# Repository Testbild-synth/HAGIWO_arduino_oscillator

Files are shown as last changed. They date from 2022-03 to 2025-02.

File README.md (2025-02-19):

# HAGIWO 019/022/023 Triple Oscillator (FM/CHORD/ADDITIVE)
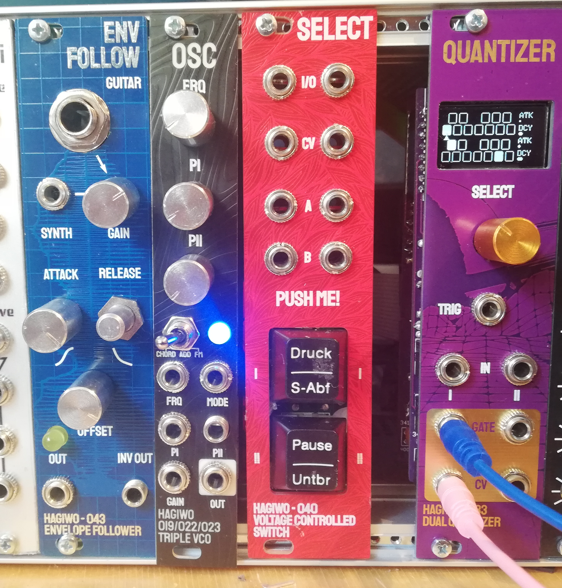
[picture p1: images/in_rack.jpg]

4HP through hole version of the HAGIWO FM/additive/chord oscillator with mode switch and gain input.

This module is basically my PCB version of the HAGIWO osc, heavily inspired by [luis lutz version](https://github.com/luislutz/Arduino-VDCO).
The main difference is since I could not get his code to work without major audio problems, I rewrote the entire thing myself.

The module combines three different oscillators from HAGIWO,  with a mode switch (and mode cv input) to switch between them.
Additionally, it has a gain input that normals so that it is only used when you plug in a jack.

### STATUS: Revision 1.1 PCB with slight modifications to make the build easier.

## Hardware and PCB
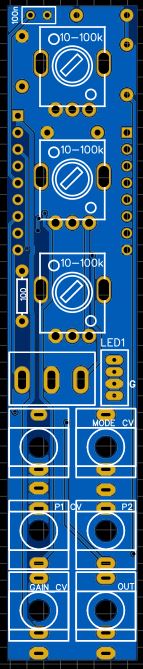
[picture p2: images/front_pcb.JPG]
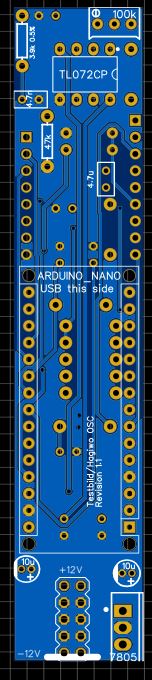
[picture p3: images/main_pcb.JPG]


You can find the schematic and BOM in the root folder.
For the potentiometers, any value between 10k and 100k should be fine.

The module has three PCBs: a panel PCB, a main PCB and a controls pcb.
You can order them on any common PCB manufacturing service, I used JLCPCB. For the circuit PCBs, standard settings should be fine.
For the panel, since it has copper exposed, make sure to choose a lead free surface finish (LeadFree HASL, ENIG) and/or spraypaint your panels so that you don't get lead on your hands.

Assembly is pretty straight forward. Since it is so crowded, make sure to do the resistors first before the headers so you have more space to work.

Also make sure to put the headers connecting both PCBs in the correct direction so that the arduino faces to the back.

The only thing there is to tune is a trimpot that sets output gain (as arduino is 0-5V output and I wanted to be able to make mine louder). Tune it to your liking.

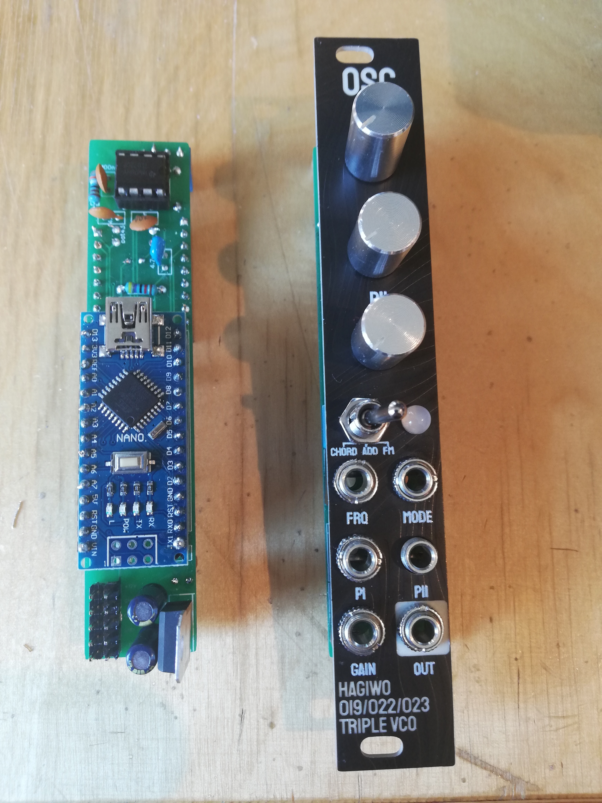
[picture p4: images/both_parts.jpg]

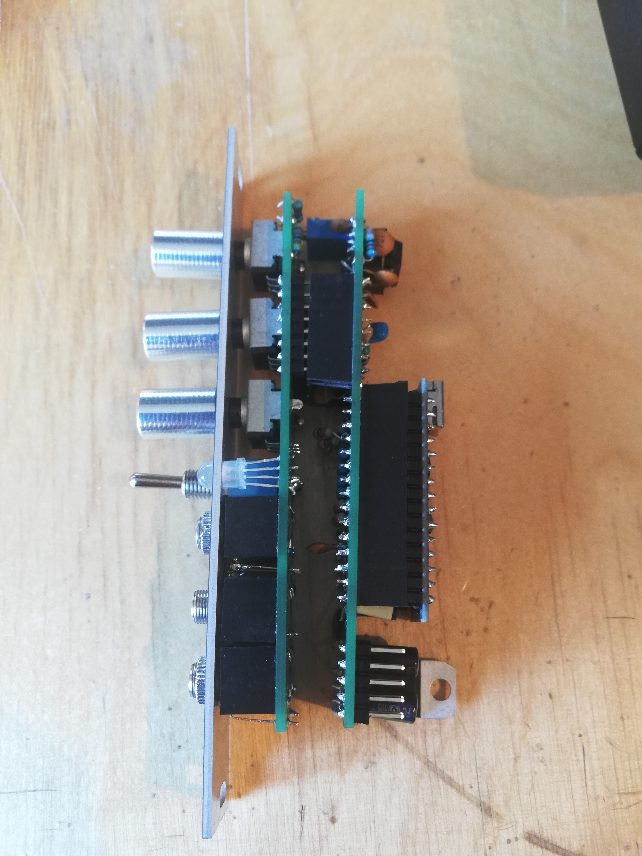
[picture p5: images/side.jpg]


## Build

Most of the build is relatively straight forward. be sure to actually have fitting values for the resistors that need to be precise. These are indicated with % on the board and in the bom.      
One thing to watch out for is that due to size constraints I oriented one row of thonkiconn jacks to face another one and have the grounds go into the same hole.
So top two rows face each other, ground legs go into the same hole.

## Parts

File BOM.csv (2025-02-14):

Name | Designator | Footprint | Quantity | Part/Comment | Link
4.7n | C1,C2,C3,C4 | RAD-0.1 | 4 | through hole ceramic capacitor
10n | C5 | RAD-0.1 | 1 | through hole ceramic capacitor
4.7u | C6 | RAD-0.1 | 1 | through hole ceramic capacitor
10u | C7,C8 | CAP-D4.0×F1.5 | 2 | through hole electrolytic capacitor, 25v
100n | C9,C10,C11,C12 | RAD-0.1 | 4 | through hole ceramic capacitor
BAT43 | D1,D2 | DO-34_BD1.6-L3.0-P7.00-D0.6-RD | 2 | through hole schottky diode
EURORACK_POWERHEADER | EP1 | EURORACK_POWER | 1 | Power header
10-100k | FRQ,P1_POT,P2_POT | R09-5KΩ | 3 | Rv09 Style Potentiometer. | https://de.aliexpress.com/item/1005002222402620.html
100k | GAIN | TRIMPOT | 1 | through hole trimpot | https://de.aliexpress.com/item/1005006157105408.html
Header-Male-2.54_1x8 | H1,H2 | HDR-TH_8P-P2.54-V-M | 2 | Male and female 2.54mm header 1x8
HDR-M-2.54_1x9 | J1,J6 | HDR-M-2.54_1X9 | 2 | Male and female 2.54mm header 1x9
P1_CV, MODE_CV, P2CV,GAIN_CV,V_OCT,OUT | J2, J3, J4, J5, J7, J8 | THONKICONN_1 | 6 | Thonkiconn mono 3.5mm jack | https://de.aliexpress.com/item/4000105739424.html cheapest I could get
LED RGB | LED1 | GEK_RGB_LED | 1 | 4 pin RGB led, like this: | https://www.reichelt.de/de/de/shop/produkt/led_5_mm_bedrahtet_4-pin_rot_gruen_blau_700_1300_300_mcd_60-231040
22k | R1,R2,R7 | R_AXIAL-0.3 | 3 | through hole resistor
499k 0.5% | R3 | R_AXIAL-0.3 | 1 | through hole resistor (accuracy important)
3.9k 0.5% | R4,R9 | R_AXIAL-0.3 | 2 | through hole resistor (accuracy important)
4k7 | R5,R6,R8 | R_AXIAL-0.3 | 3 | through hole resistor
220 | R10 | R_AXIAL-0.3 | 1 | through hole resistor
47k | R11,R14 | R_AXIAL-0.3 | 2 | through hole resistor
100 | R12 | R_AXIAL-0.3 | 1 | through hole resistor
330k | R13 | R_AXIAL-0.3 | 1 | through hole resistor
1k | R15 | R_AXIAL-0.3 | 1 | through hole resistor
68k | R16 | R_AXIAL-0.3 | 1 | through hole resistor
ARDUINO_NANO | U1 | ARDUINO_NANO_WITHMOUNTINGHOLES | 1 | It’s an arduino
7805 | U3 | TO-220-3_L10.0-W4.5-P2.54-L | 1 | L7805CV-DG Voltage regulator
TOGGLE SWITCH SPDT | U4 | MINI TOGGLE SWITCH SPDT ON-ON | 1 | Mini Toggle Switch SPDT On-OFF-ON MST 103 style | https://de.aliexpress.com/item/4000638047913.html
TL072CP | U2 | DIP-8_L9.4-W6.4-P2.54-LS9.1-BL | 1 | TL072CP DIP8 opamp

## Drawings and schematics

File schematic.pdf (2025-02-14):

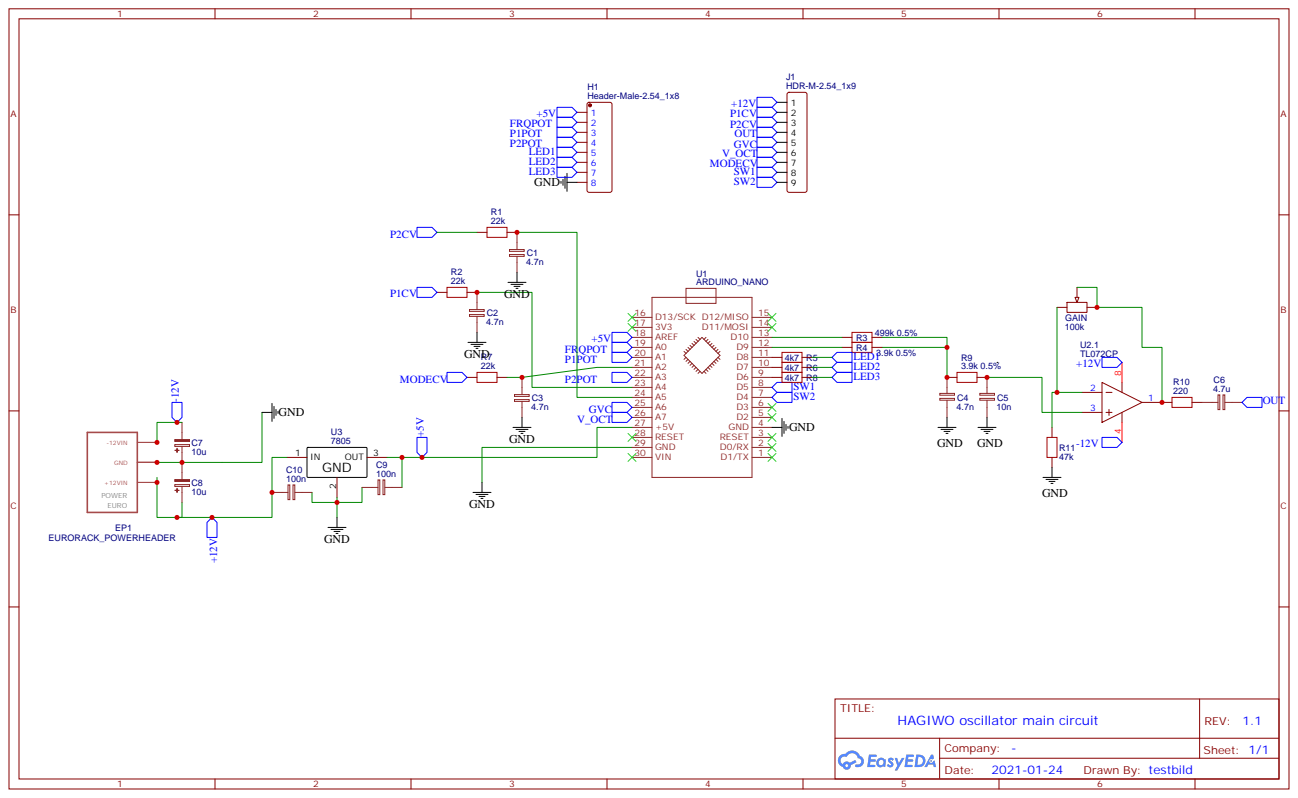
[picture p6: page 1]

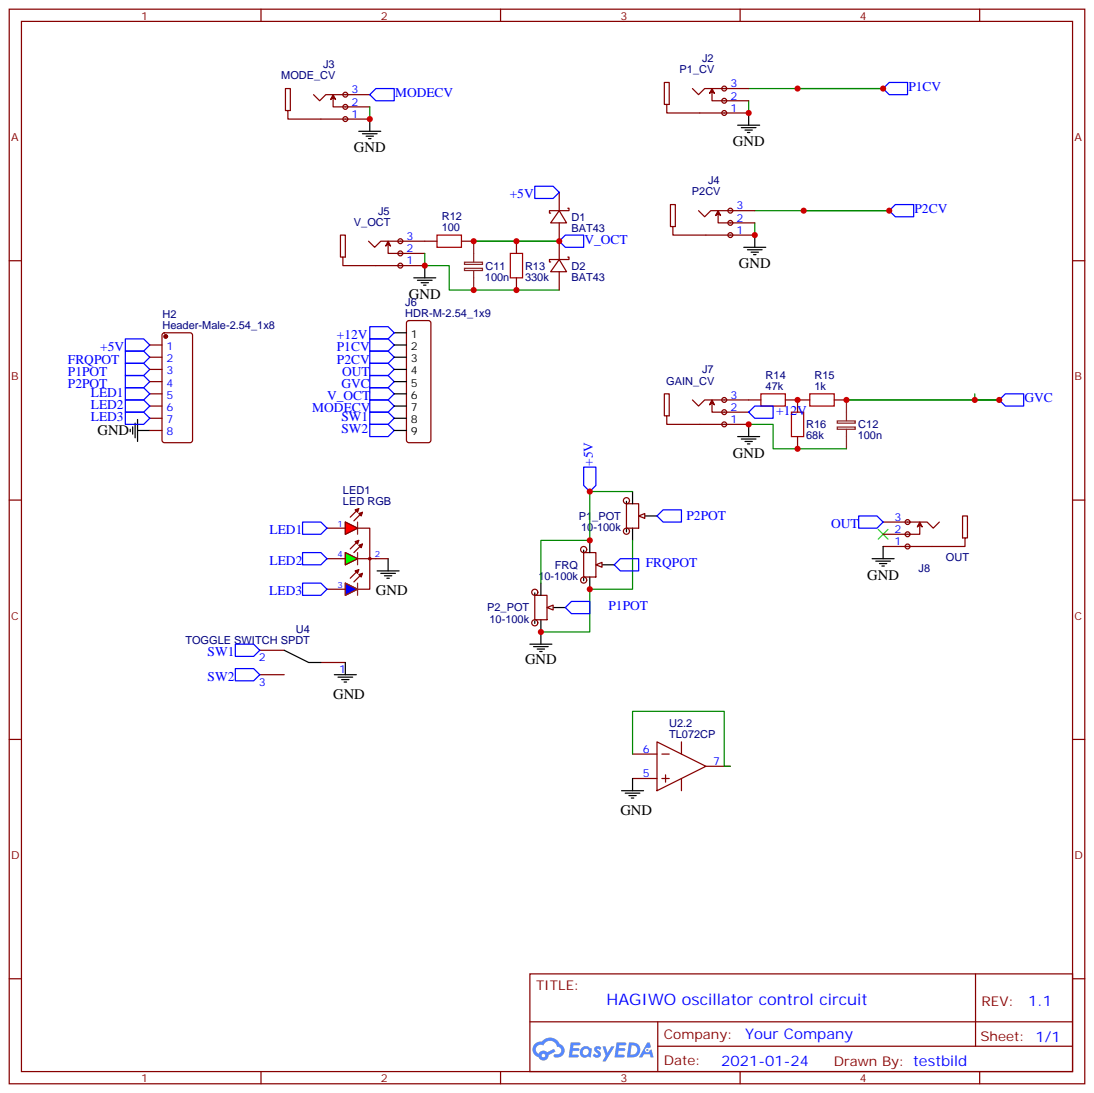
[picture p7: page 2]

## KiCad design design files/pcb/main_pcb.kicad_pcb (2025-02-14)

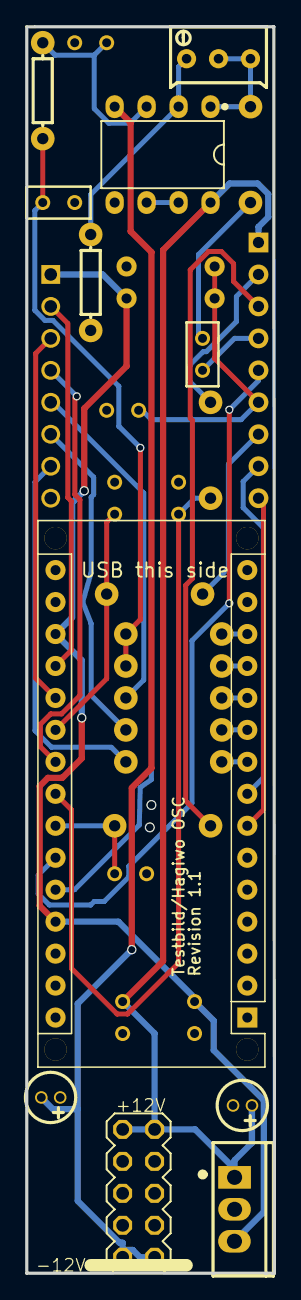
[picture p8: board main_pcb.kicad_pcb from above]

Board: 2 copper layers, 19.7 x 99.1 mm, 30 parts (0 on the bottom side), 32 nets.

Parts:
C1, C2, C3, C4: 4.7n; RAD-0.1
C5: 10n; RAD-0.1
C6: 4.7u; RAD-0.1
C7, C8: 10u; CAP-D4.0×F1.5
C9, C10, C11: 100n; RAD-0.1
D1, D2: BAT43; DO-34_BD1.6-L3.0-P7.00-D0.6-RD
GAIN: 100k; TRIMPOT
H1: Header-Male-2.54_1x8; HDR-TH_8P-P2.54-V-M
J1: HDR-M-2.54_1x9; HDR-M-2.54_1X9
R1, R2, R7: 22k; R_AXIAL-0.3
R3: 499k 0.5%; R_AXIAL-0.3
R4, R9: 3.9k 0.5%; R_AXIAL-0.3
R5, R6, R8: 4k7; R_AXIAL-0.3
R10: 220; R_AXIAL-0.3
R11: 47k; R_AXIAL-0.3
U1: ARDUINO_NANO; ARDUINO_NANO_WITHMOUNTINGHOLES
U2: TL072CP; DIP-8_L9.4-W6.4-P2.54-LS9.1-BL
U3: 7805; TO-220-3_L10.0-W4.5-P2.54-L

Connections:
+5V: C9.2, D1.1, H1.1, U1.18, U1.27, U3.3
+12V: C8.1, C10.1, J1.1, U2.8, U3.1
-12V: C7.2, U2.4
C4_1: C4.1, R3.2, R4.2, R9.1
FRQPOT: H1.2, U1.19
GND: C1.1, C2.1, C3.1, C4.2, C5.2, C7.1, C8.2, C9.1, C10.2, C11.1, D2.2, H1.8, R11.1, U1.4, U1.29, U2.5, U3.2
GVC: J1.5, U1.25
LED1: H1.5, R5.2
LED2: H1.6, R6.2
LED3: H1.7, R8.2
MODECV: J1.7, R7.2
OUT: C6.2, J1.4
P1CV: J1.2, R2.2
P1POT: H1.3, U1.20
P2CV: J1.3, R1.2
P2POT: H1.4, U1.22
R9_2: C5.1, R9.2, U2.3
R10_1: C6.1, R10.1
SW1: J1.8, U1.8
SW2: J1.9, U1.7
U1_9: R8.1, U1.9
U1_10: R6.1, U1.10
U1_11: R5.1, U1.11
U1_12: R4.1, U1.12
U1_13: R3.1, U1.13
U1_21: C3.2, R7.1, U1.21
U1_23: C2.2, R2.1, U1.23
U1_24: C1.2, R1.1, U1.24
U2_1: GAIN.2, GAIN.3, R10.2, U2.1
U2_2: GAIN.1, R11.2, U2.2
U2_6: U2.6, U2.7
V_OCT: C11.2, D1.2, D2.1, J1.6, U1.26

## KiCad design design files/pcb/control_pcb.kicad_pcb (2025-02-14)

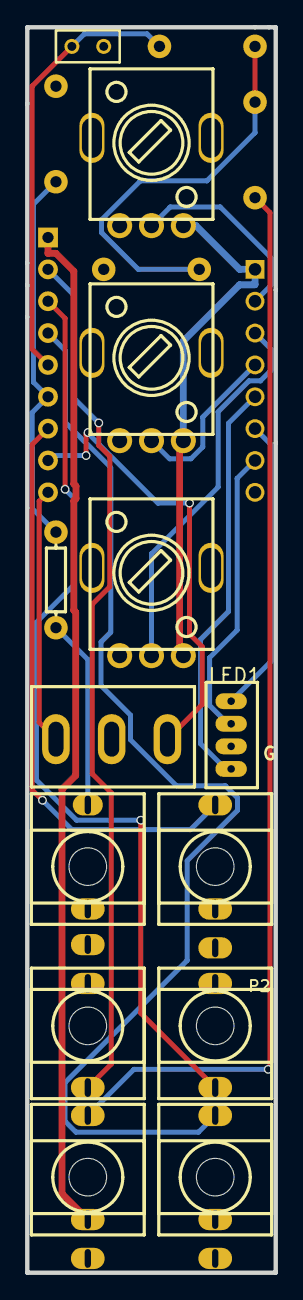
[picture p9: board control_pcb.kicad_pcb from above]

Board: 2 copper layers, 19.8 x 99.3 mm, 17 parts (0 on the bottom side), 18 nets.

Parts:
C12: 100n; RAD-0.1
FRQ: 10-100k; R09-5KΩ
H2: Header-Male-2.54_1x8; HDR-TH_8P-P2.54-V-M
J1: HDR-M-2.54_1x9; HDR-M-2.54_1X9
J2: P1_CV; THONKICONN_1
J3: MODE_CV; THONKICONN_1
J7: GAIN_CV; THONKICONN_1
J8: OUT; THONKICONN_1
LED1: LED RGB; GEK_RGB_LED
P1_POT, P2_POT: 10-100k; R09-5KΩ
R12: 100; R_AXIAL-0.3
R13: 330k; R_AXIAL-0.3
R14: 47k; R_AXIAL-0.3
R15: 1k; R_AXIAL-0.3
R16: 68k; R_AXIAL-0.3
U4: TOGGLE SWITCH SPDT; MINI TOGGLE SWITCH SPDT ON-ON

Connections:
+5V: FRQ.3, H2.1, P1_POT.3, P2_POT.3
+12V: J1.1, J7.2
FRQPOT: FRQ.2, H2.2
GND: C12.1, FRQ.1, H2.8, J2.1, J2.2, J3.1, J3.2, J7.1, J8.1, LED1.2, P1_POT.1, P2_POT.1, R13.2, R16.2, U4.1
GVC: C12.2, J1.5, R15.1
J7_3: J7.3, R14.2
LED1: H2.5, LED1.1
LED2: H2.6, LED1.4
LED3: H2.7, LED1.3
MODECV: J1.7, J3.3
OUT: J1.4, J8.3
P1CV: J1.2, J2.3
P1POT: H2.3, P2_POT.2
P2POT: H2.4, P1_POT.2
R14_1: R14.1, R15.2, R16.1
SW1: J1.8, U4.2
SW2: J1.9, U4.3
V_OCT: J1.6, R12.1, R13.1

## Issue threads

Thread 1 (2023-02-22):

Panel PCB has errors.

tomsteed, 2023-02-22:
Hi,
The panel pcb has errors with the jack sockets. 3 stacked each side should mean 9 solder points, 3 per socket. There are only 8 so the sockets wont fit.
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

Testbild-synth, 2023-02-22:
This is deliberate to minimize size. The holes are wider so you can fit two
opposing ground leads into the same hole. Its slightly uncommon but I've
seen other builds do this too and imo it's not too much of a hassle when
building.

tomsteed ***@***.***> schrieb am Mi., 22. Feb. 2023, 21:09:

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

tomsteed, 2023-02-22:
Thank you. Just did a dry fit and it will work.

Closed 2023-02-22.

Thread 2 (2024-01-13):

Discrepancy of capacitor count

aspertime, 2024-01-13:
The BOM and schematic are showing a count of 5 x 100nf capacitors in this build, while the board design only accommodates 3.

rsholmes, 2024-01-13:
The schematic, BOM, and `main_pcb.kicad_pcb` are older than the Gerbers and `main_pcb_easyeda.json`. Presumably they're not reflecting the latest version of the design.

Testbild-synth, 2025-02-13:
sorry for the late response, I will do a revision today that should clear up some of these minor issues

Testbild-synth, 2025-02-14:
uploaded a new revision that correctly has 4 100nf caps in the BOM

Closed 2025-02-14.

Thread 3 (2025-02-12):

Confused about the specific model of the switch

takuya2516, 2025-02-12:
First of all, thank you for the open-source project. I have found that several switch packages I have on hand are incompatible. May I ask what specific model you are using?

takuya2516, 2025-02-13:
> yes the footprint is a bit shit. So MST103 switches do exist with smaller lugs (see here, 2mm https://handsontec.com/index.php/product/toggle-switch-mts-103-on-off-on-spdt-6a-125vac/) or you just buy a regular one and use pliers to press the lugs from the side until they are small enough. Or you can wait I have other small issues with the PCB anyways and I could upload a new version in the evening today

thanks a lot . i have found what i need. btw, many panel files u uploaded in your projects seem to have something wrong with the holes on the pcb. and i dont know how to turn the SVG files to the format that i can edit on EDA----please tell me the way, thanks !

Testbild-synth, 2025-02-14:
uploaded a new revision with bigger holes and cleared up the BOM wrt switch type

Testbild-synth, 2025-02-14:
I have also noticed the issue it is from a bad export setting on my kicad. I will re-export the panel as well since now this problem is fixed on my newer designs I think

Testbild-synth, 2025-02-14:
everything should be there now

takuya2516, 2025-02-14:
appreciate it

takuya2516, 2025-02-14:
appreciate it

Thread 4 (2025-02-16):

Soldering of the 3.5mm audio jack

takuya2516, 2025-02-16:
hi,every audio jack has three holes .But i noticed that jacks in the middle only have 2 holes. How should i
solve them?

Testbild-synth, 2025-02-19:
put both grounds in the middle in one hole or connect the lugs together above the hole. I will put a thing about it in the readme

Closed 2025-02-19.

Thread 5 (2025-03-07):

Panel borked?

poetaster, 2025-03-07:
I was just checking the panel design svg since I wanted to change the labels a bit (I also have some alternate firmware)  but I noticed the newest svg is borked?

Thanks for all your work!

poetaster, 2025-03-07:
Ooff, just checked the gerbers and they look borked, too. This is a screensnap from jlc's gerber view.

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

Testbild-synth, 2025-03-07:
Hi Mark,

Regarding the svg I suspect this is because the text is saved as a font not
as a path, and it will look wonky if you don't have the font on your
system. I can re export with the text converted to paths tomorrow.

Regarding the Gerbers, I think they should work fine. Jlc viewer is
sometimes bad in preview, try the pcbway Gerber viewers or the detailed
layer view on Jlc. But I will also check them tomorrow

Mark Washeim ***@***.***> schrieb am Fr., 7. März 2025, 21:07:

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

Testbild-synth, 2025-03-08:
@poetaster  I checked [pcbway gerber viewer](https://www.pcbway.com/project/OnlineGerberViewer.html) and the panel looks fine. As I said I and others have also ordered these before on jlc and tey work. For the svg I did a re-export with the text hopefully corrected to paths meaning you should be able to use it without having the font.
If you have other issues with it let me know

poetaster, 2025-03-08:
> [@poetaster](https://github.com/poetaster) I checked [pcbway gerber viewer](https://www.pcbway.com/project/OnlineGerberViewer.html) and the panel looks fine.

I just checked in kicad's gerber viewer and the gerbers were fine.

>  As I said I and others have also ordered these before on jlc and tey work. For the svg I did a re-export with the text hopefully corrected to paths meaning you should be able to use it without having the font. If you have other issues with it let me know

Thanks! I wanted to change a couple of things, since I'm going to use this for some alternate firmware. When I've got the boards and it's running, I'll submit some alt firmware that will work well with this layout.

Thanks again for all your labours!

Closed 2025-03-08.

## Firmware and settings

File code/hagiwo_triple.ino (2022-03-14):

#include <MozziGuts.h>
#include <Oscil.h>
#include <tables/sin2048_int8.h>
#include <tables/saw2048_int8.h> 
#include <tables/triangle_hermes_2048_int8.h>
#include <tables/square_no_alias_2048_int8.h>
#include <tables/triangle_dist_cubed_2048_int8.h>

#include <mozzi_fixmath.h>

#define CONTROL_RATE 128 

#define V_OCT_PIN A7
#define FREQ_PIN A0
#define P1_POT_PIN A1
#define P1_CV_PIN A4
#define P2_POT_PIN A3
#define P2_CV_PIN A5
#define SW_PIN_1 4
#define SW_PIN_2 5
#define LED_1_PIN 6
#define LED_2_PIN 7
#define LED_3_PIN 8
#define GAIN_CV_PIN A6
#define MODE_CV_PIN A2

Oscil<SIN2048_NUM_CELLS, AUDIO_RATE> osc1(SIN2048_DATA);
Oscil<SIN2048_NUM_CELLS, AUDIO_RATE> osc2(SIN2048_DATA);
Oscil<SIN2048_NUM_CELLS, AUDIO_RATE> osc3(SIN2048_DATA);
Oscil<SIN2048_NUM_CELLS, AUDIO_RATE> osc4(SIN2048_DATA);
Oscil<SIN2048_NUM_CELLS, AUDIO_RATE> osc5(SIN2048_DATA);
Oscil<SIN2048_NUM_CELLS, AUDIO_RATE> osc6(SIN2048_DATA);
Oscil<SIN2048_NUM_CELLS, AUDIO_RATE> osc7(SIN2048_DATA);
Oscil<SIN2048_NUM_CELLS, AUDIO_RATE> osc8(SIN2048_DATA);

uint16_t freq_val = 0;
uint16_t v_oct_val = 0;
uint16_t p1_pot_val = 0;
uint16_t p1_cv_val = 0;
uint16_t p2_pot_val = 0;
uint16_t p2_cv_val = 0;
int gain_val = 0;
uint8_t mode = 0;
uint8_t mode_val = 0;

///additive variables
int ADD_freq1 = 110;//base freq of OSC1
int ADD_freqv1 = 440;// freq1 apply voct
byte ADD_gain = 127;
uint8_t ADD_harm_knob = 0;
////////

////chord variables
int freq1 = 110;//base freq

int freqv1 = 440;//apply voct
int freqv2 = 440;
int freqv3 = 440;
int freqv4 = 440;
int freqv5 = 440;

byte note1 = 0;//Root
byte note2 = 0;//2nd
byte note3 = 0;//3rd
byte note4 = 0;//4th
byte note5 = 0;//Root

byte inv_aply1 = 0; //0 = no inv , 1 = inv , Root
byte inv_aply2 = 0; //2nd
byte inv_aply3 = 0; //3rd
byte inv_aply4 = 0; //4th
bool inv_aply5 = 0; //0 = no output root sound , 1 = output root sound

int inv = 0;
int inv_knob = 0;
int chord = 0;
byte wave = 0;
////////

////FM variables
Q16n16 deviation;
Q16n16 mod_freq, knob_freq;
///////

const static byte chord_table[8][4]PROGMEM = {
 {  0,  68, 119,  205,  },//Maj
 { 0,  68, 119,  187,  },//Maj7
 { 0,  68, 119,  239,  },//Majadd9
 { 0,  34, 119,  205,  },//sus2
 { 0,  51, 119,  239,  },//minadd9
 { 0,  51, 119,  170,  },//min7
 { 0,  51, 119,  205,  },//min
 { 0,  0,  0,  0,  }//root
};


const static float voctpow[1024] PROGMEM = {
 0,  0.004882, 0.009765, 0.014648, 0.019531, 0.024414, 0.029296, 0.034179, 0.039062, 0.043945, 0.048828, 0.05371,  0.058593, 0.063476, 0.068359, 0.073242, 0.078125, 0.083007, 0.08789,  0.092773, 0.097656, 0.102539, 0.107421, 0.112304, 0.117187, 0.12207,  0.126953, 0.131835, 0.136718, 0.141601, 0.146484, 0.151367, 0.15625,  
 0.161132, 0.166015, 0.170898, 0.175781, 0.180664, 0.185546, 0.190429, 0.195312, 0.200195, 0.205078, 0.20996,  0.214843, 0.219726, 0.224609, 0.229492, 0.234375, 0.239257, 0.24414,  0.249023, 0.253906, 0.258789, 0.263671, 0.268554, 0.273437, 0.27832,  0.283203, 0.288085, 0.292968, 0.297851, 0.302734, 0.307617, 0.3125, 0.317382, 
 0.322265, 0.327148, 0.332031, 0.336914, 0.341796, 0.346679, 0.351562, 0.356445, 0.361328, 0.36621,  0.371093, 0.375976, 0.380859, 0.385742, 0.390625, 0.395507, 0.40039,  0.405273, 0.410156, 0.415039, 0.419921, 0.424804, 0.429687, 0.43457,  0.439453, 0.444335, 0.449218, 0.454101, 0.458984, 0.463867, 0.46875,  0.473632, 0.478515,
  0.483398, 0.488281, 0.493164, 0.498046, 0.502929, 0.507812, 0.512695, 0.517578, 0.52246,  0.527343, 0.532226, 0.537109, 0.541992, 0.546875, 0.551757, 0.55664,  0.561523, 0.566406, 0.571289, 0.576171, 0.581054, 0.585937, 0.59082,  0.595703, 0.600585, 0.605468, 0.610351, 0.615234, 0.620117, 0.625,  0.629882, 0.634765, 0.639648, 
  0.644531, 0.649414, 0.654296, 0.659179, 0.664062, 0.668945, 0.673828, 0.67871,  0.683593, 0.688476, 0.693359, 0.698242, 0.703125, 0.708007, 0.71289,  0.717773, 0.722656, 0.727539, 0.732421, 0.737304, 0.742187, 0.74707,  0.751953, 0.756835, 0.761718, 0.766601, 0.771484, 0.776367, 0.78125,  0.786132, 0.791015, 0.795898, 0.800781, 0.805664, 0.810546, 
  0.815429, 0.820312, 0.825195, 0.830078, 0.83496,  0.839843, 0.844726, 0.849609, 0.854492, 0.859375, 0.864257, 0.86914,  0.874023, 0.878906, 0.883789, 0.888671, 0.893554, 0.898437, 0.90332,  0.908203, 0.913085, 0.917968, 0.922851, 0.927734, 0.932617, 0.9375, 0.942382, 0.947265, 0.952148, 0.957031, 0.961914, 0.966796, 0.971679, 0.976562, 0.981445, 0.986328, 0.99121,  0.996093, 1.000976, 1.005859, 1.010742, 1.015625, 1.020507, 1.02539,  1.030273, 1.035156, 1.040039, 1.044921, 1.049804, 1.054687, 1.05957,  1.064453, 1.069335, 1.074218, 1.079101, 1.083984, 
  1.088867, 1.09375,  1.098632, 1.103515, 1.108398, 1.113281, 1.118164, 1.123046, 1.127929, 1.132812, 1.137695, 1.142578, 1.14746,  1.152343, 1.157226, 1.162109, 1.166992, 1.171875, 1.176757, 1.18164,  1.186523, 1.191406, 1.196289, 1.201171, 1.206054, 1.210937, 1.21582,  1.220703, 1.225585, 1.230468, 1.235351, 1.240234, 1.245117, 1.25, 1.254882, 1.259765, 1.264648, 1.269531, 1.274414, 1.279296, 1.284179, 1.289062, 1.293945, 1.298828, 1.30371,  1.308593, 1.313476, 1.318359, 1.323242, 1.328125, 1.333007, 1.33789,  1.342773, 1.347656, 1.352539, 1.357421, 1.362304, 1.367187, 1.37207,  1.376953, 1.381835, 1.386718, 1.391601, 1.396484, 1.401367, 1.40625,  1.411132, 1.416015, 1.420898, 1.425781, 1.430664, 1.435546, 1.440429, 1.445312, 1.450195, 1.455078, 1.45996,  1.464843, 1.469726, 1.474609, 1.479492, 1.484375, 1.489257, 1.49414,  1.499023, 1.503906, 1.508789, 1.513671, 1.518554, 1.523437, 1.52832,  1.533203, 1.538085, 1.542968, 1.547851, 1.552734, 1.557617, 1.5625, 1.567382, 1.572265, 1.577148, 1.582031, 1.586914, 1.591796, 1.596679, 1.601562, 1.606445, 1.611328, 1.61621,  1.621093, 1.625976, 1.630859, 1.635742, 1.640625, 1.645507, 1.65039,  1.655273, 1.660156, 1.665039, 1.669921, 1.674804, 1.679687, 1.68457,  1.689453, 1.694335, 1.699218, 1.704101, 1.708984, 1.713867, 1.71875,  1.723632, 1.728515, 1.733398, 1.738281, 1.743164, 1.748046, 1.752929, 1.757812, 1.762695, 1.767578, 1.77246,  1.777343, 1.782226, 1.787109, 1.791992, 1.796875, 1.801757, 1.80664,  1.811523, 1.816406, 1.821289, 1.826171, 1.831054, 1.835937, 1.84082,  1.845703, 1.850585, 1.855468, 1.860351, 1.865234, 1.870117, 1.875,  1.879882, 1.884765, 1.889648, 1.894531, 1.899414, 1.904296, 1.909179, 1.914062, 1.918945, 1.923828, 1.92871,  1.933593, 1.938476, 1.943359, 1.948242, 1.953125, 1.958007, 1.96289,  1.967773, 1.972656, 1.977539, 1.982421, 1.987304, 1.992187, 1.99707,  2.001953, 2.006835, 2.011718, 2.016601, 2.021484, 2.026367, 2.03125,  2.036132, 2.041015, 2.045898, 2.050781, 2.055664, 2.060546, 2.065429, 2.070312, 2.075195, 2.080078, 2.08496,  2.089843, 2.094726, 2.099609, 2.104492, 2.109375, 2.114257, 2.11914,  2.124023, 2.128906, 2.133789, 2.138671, 2.143554, 2.148437, 2.15332,  2.158203, 2.163085, 2.167968, 2.172851, 2.177734, 2.182617, 2.1875, 2.192382, 2.197265, 2.202148, 2.207031, 2.211914, 2.216796, 2.221679, 2.226562, 2.231445, 2.236328, 2.24121,  2.246093, 2.250976, 2.255859, 2.260742, 2.265625, 2.270507, 2.27539,  2.280273, 2.285156, 2.290039, 2.294921, 2.299804, 2.304687, 2.30957,  2.314453, 2.319335, 2.324218, 2.329101, 2.333984, 2.338867, 2.34375,  2.348632, 2.353515, 2.358398, 2.363281, 2.368164, 2.373046, 2.377929, 2.382812, 2.387695, 2.392578, 2.39746,  2.402343, 2.407226, 2.412109, 2.416992, 2.421875, 2.426757, 2.43164,  2.436523, 2.441406, 2.446289, 2.451171, 2.456054, 2.460937, 2.46582,  2.470703, 2.475585, 2.480468, 2.485351, 2.490234, 2.495117, 2.5,  2.504882, 2.509765, 2.514648, 2.519531, 2.524414, 2.529296, 2.534179, 2.539062, 2.543945, 2.548828, 2.55371,  2.558593, 2.563476, 2.568359, 2.573242, 2.578125, 2.583007, 2.58789,  2.592773, 2.597656, 2.602539, 2.607421, 2.612304, 2.617187, 2.62207,  2.626953, 2.631835, 2.636718, 2.641601, 2.646484, 2.651367, 2.65625,  2.661132, 2.666015, 2.670898, 2.675781, 2.680664, 2.685546, 2.690429, 2.695312, 2.700195, 2.705078, 2.70996,  2.714843, 2.719726, 2.724609, 2.729492, 2.734375, 2.739257, 2.74414,  2.749023, 2.753906, 2.758789, 2.763671, 2.768554, 2.773437, 2.77832,  2.783203, 2.788085, 2.792968, 2.797851, 2.802734, 2.807617, 2.8125, 2.817382, 2.822265, 2.827148, 2.832031, 2.836914, 2.841796, 2.846679, 2.851562, 2.856445, 2.861328, 2.86621,  2.871093, 2.875976, 2.880859, 2.885742, 2.890625, 2.895507, 2.90039,  2.905273, 2.910156, 2.915039, 2.919921, 2.924804, 2.929687, 2.93457,  2.939453, 2.944335, 2.949218, 2.954101, 2.958984, 2.963867, 2.96875,  2.973632, 2.978515, 2.983398, 2.988281, 2.993164, 2.998046, 3.002929, 3.007812, 3.012695, 3.017578, 3.02246,  3.027343, 3.032226, 3.037109, 3.041992, 3.046875, 3.051757, 3.05664,  3.061523, 3.066406, 3.071289, 3.076171, 3.081054, 3.085937, 3.09082,  3.095703, 3.100585, 3.105468, 3.110351, 3.115234, 3.120117, 3.125,  3.129882, 3.134765, 3.139648, 3.144531, 3.149414, 3.154296, 3.159179, 3.164062, 3.168945, 3.173828, 3.17871,  3.183593, 3.188476, 3.193359, 3.198242, 3.203125, 3.208007, 3.21289,  3.217773, 3.222656, 3.227539, 3.232421, 3.237304, 3.242187, 3.24707,  3.251953, 3.256835, 3.261718, 3.266601, 3.271484, 3.276367, 3.28125,  3.286132, 3.291015, 3.295898, 3.300781, 3.305664, 3.310546, 3.315429, 3.320312, 3.325195, 3.330078, 3.33496,  3.339843, 3.344726, 3.349609, 3.354492, 3.359375, 3.364257, 3.36914,  3.374023, 3.378906, 3.383789, 3.388671, 3.393554, 3.398437, 3.40332,  3.408203, 3.413085, 3.417968, 3.422851, 3.427734, 3.432617, 3.4375, 3.442382, 3.447265, 3.452148, 3.457031, 3.461914, 3.466796, 3.471679, 3.476562, 3.481445, 3.486328, 3.49121,  3.496093, 3.500976, 3.505859, 3.510742, 3.515625, 3.520507, 3.52539,  3.530273, 3.535156, 3.540039, 3.544921, 3.549804, 3.554687, 3.55957,  3.564453, 3.569335, 3.574218, 3.579101, 3.583984, 3.588867, 3.59375,  3.598632, 3.603515, 3.608398, 3.613281, 3.618164, 3.623046, 3.627929, 3.632812, 3.637695, 3.642578, 3.64746,  3.652343, 3.657226, 3.662109, 3.666992, 3.671875, 3.676757, 3.68164,  3.686523, 3.691406, 3.696289, 3.701171, 3.706054, 3.710937, 3.71582,  3.720703, 3.725585, 3.730468, 3.735351, 3.740234, 3.745117, 3.75, 3.754882, 3.759765, 3.764648, 3.769531, 3.774414, 3.779296, 3.784179, 3.789062, 3.793945, 3.798828, 3.80371,  3.808593, 3.813476, 3.818359, 3.823242, 3.828125, 3.833007, 3.83789,  3.842773, 3.847656, 3.852539, 3.857421, 3.862304, 3.867187, 3.87207,  3.876953, 3.881835, 3.886718, 3.891601, 3.896484, 3.901367, 3.90625,  3.911132, 3.916015, 3.920898, 3.925781, 3.930664, 3.935546, 3.940429, 3.945312, 3.950195, 3.955078, 3.95996,  3.964843, 3.969726, 3.974609, 3.979492, 3.984375, 3.989257, 3.99414,  3.999023, 4.003906, 4.008789, 4.013671, 4.018554, 4.023437, 4.02832,  4.033203, 4.038085, 4.042968, 4.047851, 4.052734, 4.057617, 4.0625, 4.067382, 4.072265, 4.077148, 4.082031, 4.086914, 4.091796, 4.096679, 4.101562, 4.106445, 4.111328, 4.11621,  4.121093, 4.125976, 4.130859, 4.135742, 4.140625, 4.145507, 4.15039,  4.155273, 4.160156, 4.165039, 4.169921, 4.174804, 4.179687, 4.18457,  4.189453, 4.194335, 4.199218, 4.204101, 4.208984, 4.213867, 4.21875,  4.223632, 4.228515, 4.233398, 4.238281, 4.243164, 4.248046, 4.252929, 4.257812, 4.262695, 4.267578, 4.27246,  4.277343, 4.282226, 4.287109, 4.291992, 4.296875, 4.301757, 4.30664,  4.311523, 4.316406, 4.321289, 4.326171, 4.331054, 4.335937, 4.34082,  4.345703, 4.350585, 4.355468, 4.360351, 4.365234, 4.370117, 4.375,  4.379882, 4.384765, 4.389648, 4.394531, 4.399414, 4.404296, 4.409179, 4.414062, 4.418945, 4.423828, 4.42871,  4.433593, 4.438476, 4.443359, 4.448242, 4.453125, 4.458007, 4.46289,  4.467773, 4.472656, 4.477539, 4.482421, 4.487304, 4.492187, 4.49707,  4.501953, 4.506835, 4.511718, 4.516601, 4.521484, 4.526367, 4.53125,  4.536132, 4.541015, 4.545898, 4.550781, 4.555664, 4.560546, 4.565429, 4.570312, 4.575195, 4.580078, 4.58496,  4.589843, 4.594726, 4.599609, 4.604492, 4.609375, 4.614257, 4.61914,  4.624023, 4.628906, 4.633789, 4.638671, 4.643554, 4.648437, 4.65332,  4.658203, 4.663085, 4.667968, 4.672851, 4.677734, 4.682617, 4.6875, 4.692382, 4.697265, 4.702148, 4.707031, 4.711914, 4.716796, 4.721679, 4.726562, 4.731445, 4.736328, 4.74121,  4.746093, 4.750976, 4.755859, 4.760742, 4.765625, 4.770507, 4.77539,  4.780273, 4.785156, 4.790039, 4.794921, 4.799804, 4.804687, 4.80957,  4.814453, 4.819335, 4.824218, 4.829101, 4.833984, 4.838867, 4.84375,  4.848632, 4.853515, 4.858398, 4.863281, 4.868164, 4.873046, 4.877929, 4.882812, 4.887695, 4.892578, 4.89746,  4.902343, 4.907226, 4.912109, 4.916992, 4.921875, 4.926757, 4.93164,  4.936523, 4.941406, 4.946289, 4.951171, 4.956054, 4.960937, 4.96582,  4.970703, 4.975585, 4.980468, 4.985351, 4.990234, 4.995117
};
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
void loop() {
 audioHook();
}


void CHORD_setFreqs(){
  chord = constrain((p2_pot_val / 128) + (p2_cv_val / 128), 0, 7);

 //inversion setting
 inv = constrain((p1_pot_val  / 64) + (p1_cv_val / 64) , 0, 15);
   switch (inv) {
     case 0:
       inv_aply1 = 0;
       inv_aply2 = 0;
       inv_aply3 = 0;
       inv_aply4 = 0;
       inv_aply5 = 0;
       break;

     case 1:
       inv_aply1 = 1;
       inv_aply2 = 0;
       inv_aply3 = 0;
       inv_aply4 = 0;
       inv_aply5 = 0;
       break;

     case 2:
       inv_aply1 = 1;
       inv_aply2 = 1;
       inv_aply3 = 0;
       inv_aply4 = 0;
       inv_aply5 = 0;
       break;

     case 3:
       inv_aply1 = 1;
       inv_aply2 = 1;
       inv_aply3 = 1;
       inv_aply4 = 0;
       inv_aply5 = 0;
       break;

     case 4:
       inv_aply1 = 1;
       inv_aply2 = 1;
       inv_aply3 = 1;
       inv_aply4 = 1;
       inv_aply5 = 0;
       break;

     case 5:
       inv_aply1 = 2;
       inv_aply2 = 1;
       inv_aply3 = 1;
       inv_aply4 = 1;
       inv_aply5 = 0;
       break;

     case 6:
       inv_aply1 = 2;
       inv_aply2 = 2;
       inv_aply3 = 1;
       inv_aply4 = 1;
       inv_aply5 = 0;
       break;

     case 7:
       inv_aply1 = 2;
       inv_aply2 = 2;
       inv_aply3 = 2;
       inv_aply4 = 1;
       inv_aply5 = 0;
       break;

     case 8:
       inv_aply1 = 2;
       inv_aply2 = 2;
       inv_aply3 = 2;
       inv_aply4 = 1;
       inv_aply5 = 1;
       break;

     case 9:
       inv_aply1 = 2;
       inv_aply2 = 2;
       inv_aply3 = 1;
       inv_aply4 = 1;
       inv_aply5 = 1;
       break;

     case 10:
       inv_aply1 = 2;
       inv_aply2 = 1;
       inv_aply3 = 1;
       inv_aply4 = 1;
       inv_aply5 = 1;
       break;

     case 11:
       inv_aply1 = 1;
       inv_aply2 = 1;
       inv_aply3 = 1;
       inv_aply4 = 1;
       inv_aply5 = 1;
       break;

     case 12:
       inv_aply1 = 1;
       inv_aply2 = 1;
       inv_aply3 = 1;
       inv_aply4 = 0;
       inv_aply5 = 1;
       break;

     case 13:
       inv_aply1 = 1;
       inv_aply2 = 1;
       inv_aply3 = 0;
       inv_aply4 = 0;
       inv_aply5 = 1;
       break;

     case 14:
       inv_aply1 = 1;
       inv_aply2 = 0;
       inv_aply3 = 0;
       inv_aply4 = 0;
       inv_aply5 = 1;
       break;

     case 15:
       inv_aply1 = 0;
       inv_aply2 = 0;
       inv_aply3 = 0;
       inv_aply4 = 0;
       inv_aply5 = 1;
       break;
   }
 //setting chord note
   note1 = (pgm_read_byte(&(chord_table[chord][0])));
   note2 = (pgm_read_byte(&(chord_table[chord][1])));
   note3 = (pgm_read_byte(&(chord_table[chord][2])));
   note4 = (pgm_read_byte(&(chord_table[chord][3])));
   note5 = (pgm_read_byte(&(chord_table[chord][0])));
 //OSC frequency knob
 freq1 = freq_val / 4 ;
 //set wave
 if (p1_pot_val >= 1020) { //inv knob max
   wave = (p2_pot_val / 128);
 }
 freqv1 = freq1 * pow(2, (pgm_read_float(&(voctpow[v_oct_val + 205 * inv_aply1 + note1])))); //ROOT
 freqv2 = freq1 * pow(2, (pgm_read_float(&(voctpow[v_oct_val + 205 * inv_aply2 + note2])))); //2nd
 freqv3 = freq1 * pow(2, (pgm_read_float(&(voctpow[v_oct_val + 205 * inv_aply3 + note3])))); //3rd
 freqv4 = freq1 * pow(2, (pgm_read_float(&(voctpow[v_oct_val + 205 * inv_aply4 + note4])))); //4th
 freqv5 = freq1 * pow(2, (pgm_read_float(&(voctpow[v_oct_val + note5])))); //ROOT
 osc1.setFreq(freqv1); // set the frequency
 osc2.setFreq(freqv2);
 osc3.setFreq(freqv3);
 osc4.setFreq(freqv4);
 osc5.setFreq(freqv5);
}

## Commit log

2022-03-14 file upload
    [control_pcb.kicad_pcb, hagiwo_triple.kicad_pcb, main_pcb.kicad_pcb]
2022-03-14 upload BOM
    [BOM.csv]
2023-01-16 new files for fixed power lane and better spaced components
2025-02-14 revision 1.1 pcb
    mainly better footprints, slightly more space for the power adapter
    [BOM.csv, control_pcb.kicad_pcb, main_pcb.kicad_pcb]
2025-02-14 new images for 1.1 pcbs
2025-02-14 new panel for 1.1 revision
    [hagiwo_triple.kicad_pcb, panel_design.kicad_pcb]
